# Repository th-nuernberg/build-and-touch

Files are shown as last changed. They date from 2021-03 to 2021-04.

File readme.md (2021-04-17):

# DIY VR Data Gloves 

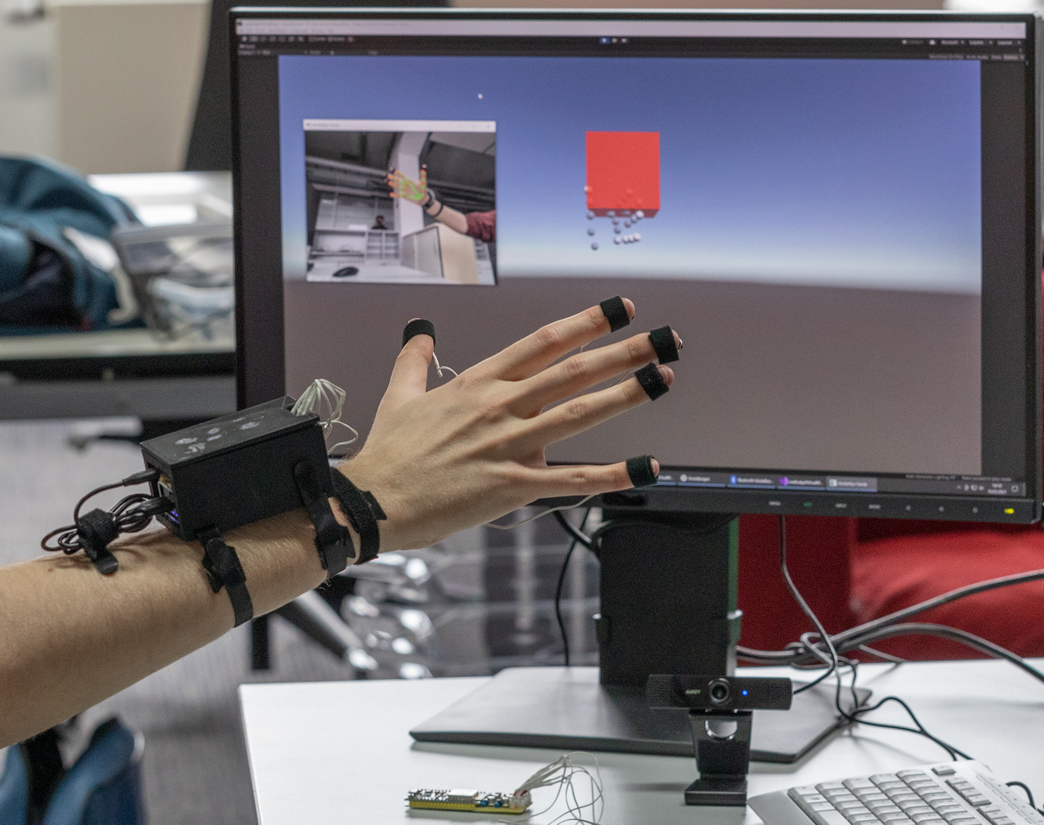
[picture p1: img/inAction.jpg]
Build and Touch in Action


## Overview
This repository provides an DIY approach to haptic feedback in virtual reality.
It is split into three components. 
- The tracking part, that is using Google's mediapipe for realtime detection of the users' fingers and hand position using an off-the-shelf webcam.
- The hardware part, that provides instruction to build the data gloves using a microcontroller and vibration actuators.
- A unity demo application.

## Work in Progress
This project is still in development and may undergo changes in the future.

## Instructions

Detailed instructions for each component can be found in the corresponding sub folders:
- [DIY Gloves](/data_gloves/readme.md)
- [Optical Tracking](/optical_tracking/readme.md)
- [Example Application](/unity_sample/readme.md)

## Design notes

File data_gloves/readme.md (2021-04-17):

# DIY Data Glove Build Instructions
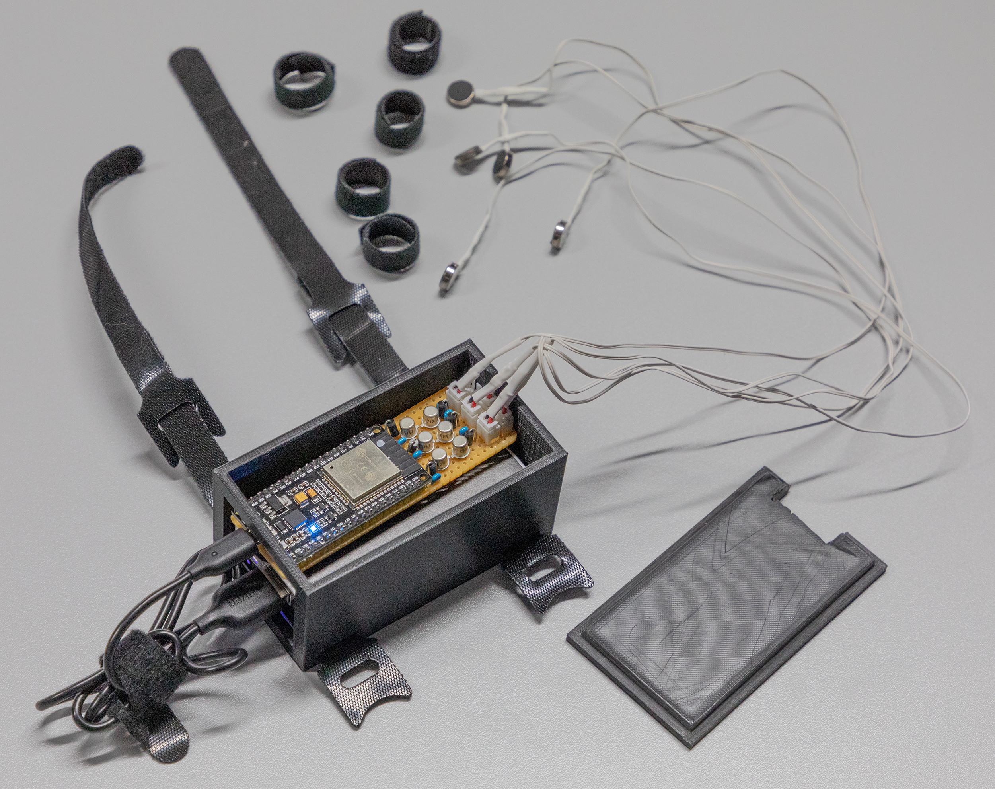
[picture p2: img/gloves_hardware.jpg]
Build and Touch in Action


The following document gives an overview of how the DIY data glove can be created. 
## Hardware Components
For one glove the following components are needed:

- 1 ESP32 microcontroller
- Power bank or other power source to power the ESP32 during use.
- **For each** finger (and palm) the following is required
    - 1 resistor (1KOhm)
    - 1 transistor (2N2222)
    - 1 diode (1N4001)
    - 1 capacitor (100nF)
    - 1 small vibration actuator

The required values may differ based on your selected components.

## Building the Hardware
The layout of the glove can be seen in the following overview.
Each actuator is connected with power and can be controlled through pulse-width modulation through an **analog** GPIO pin of the ESP32.
Depending on the exact module, the pins may vary and the spec sheet of your microcontroller should be consulted.
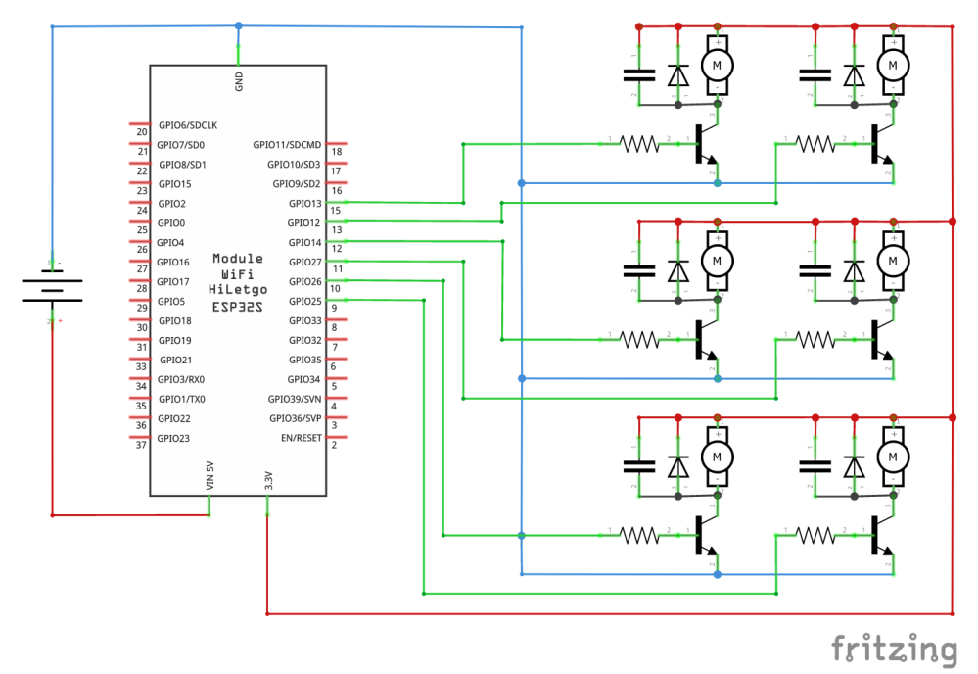
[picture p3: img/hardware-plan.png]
Hardware layout of the components


Instead of soldering the actuators directly to the other components or a soldering board it may be advised to use modular plugs instead. This way it is possible to only use a reduced set of actuators or replace a faulty one.

## Software for the Microcontroller
The ESP32 was flashed using the Arduino IDE.
The used code can be found in `data_gloves/src/hand_controller.ino`.
For easy identification, it is advised that each controller gets a unique name (e.g. left and right) if more than one esp is being used. For this, replace the string in `SerialBT.begin("Controller-right")` with your preferred name.

Depending on the used GPIO pins you may want to change the mapping of the pins in the source code.
Each finger (and the palm) get assigned an incrementing Id beginning at zero, that is later used to control the associated actuator.

The line `int fingerPins[] = { 12, 13, 14, 25, 26, 27 };` assigns each of these indices the associated GPIO pin. Therefore in this example the index finger is GPIO 13 and the PALM is mapped to GPIO 27. Feel free to change this if your pins differ.

## Connecting to Windows 10
With the hardware build and the flashed microcontroller the hardware is now ready for use.
For this connect the micro-usb port of the microcontroller to a power source. If the controller
provides an debug led it should be lit.

Connect the bluetooth dongle, if your computer doesn't have built-in bluetooth connectivity.
Going into Settings/Bluetooth the Controller should now show up when trying to connect to new devices.

## Testing the Controller
To test the implementation a simple string can be sent to the device. For this we can use [Bluetooth Serial Terminal](https://www.microsoft.com/de-de/p/bluetooth-serial-terminal/9wzdncrdfst8?activetab=pivot:overviewtab).

1. Refresh the device list and select the device you want to test (e.g. 'controller-right').
2. Press connect. We can send strings to the device.
3. Send the string "`0,255;`". One of the vibration motors should now be vibrating with full strength.
4. Send the string "`0,0;`". The same motor should stop vibrating.

If all went well the glove is ready for use in your projects.

## Protocol
The provided script of the microcontroller expects two values separated by a comma "`,`" followed by a semicolon "`;`". 
The first value is an integer that controls the actuator that should be triggered.
The second value is the intensity of the vibration. A value between 0-255. Zero is no vibration. 255 is full intensity (Note that depending on the used motor, it may not trigger for small values <50).
Multiple values can be sent with one message e.g.:
```
0,255;1,0;2,255;
```
Sets the first and third actuator to max and the second to zero intensity. All other connected actuators are unchanged!

## Fixation of the Actuators
The easy way to fixate the actuators to ones finger is the use of small velcro straps. 
For a more "sophisticated" method it is possible to the attach the actuators to a glove.
The image below shows an inner glove with six pockets in which the actuators can be placed. 
A bigger glove can worn above the inner glove so that the cables are out of the way during the usage of the glove.

TODO: Add image

## Printing an Enclosure
Additionally to the hardware an enclosure can be 3d-printed. This protects the hardware and also makes it easier to use.
The size of the case depends on the size of your hardware and power source.
An example OpenScad file is provided with 'data_gloves/enclosure.scad'.
The dimensions of the casing can be customized with the variables at the beginning of the file.
If the `strapholder` variable is set to `true` set of two holes on each side will be added, that can be used to fixate the device to ones hand (e.g. using velcro straps. See image at the top).

## Acknowledgements
These instructions are based on the initial version of the glove in "[Evaluation of different types of haptic feedback influencing the task-based presence and performance in virtual reality](https://dl.acm.org/doi/10.1145/3316782.3321536)". We thank the other team members involved there and especially Oliver Friedmann for the support during the initial development.

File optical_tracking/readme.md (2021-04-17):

# Optical Tracking

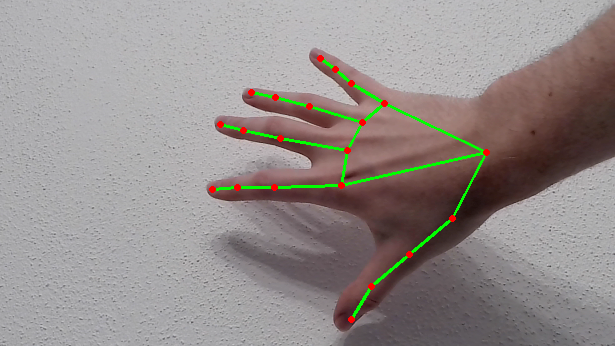
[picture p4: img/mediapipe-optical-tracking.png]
Build and Touch in Action


This folder contains the optical tracking script written in python. The application tries to connect to an tcp socket upon start and accesses the users webcam as an input device.
The hands landmarks get acquired through the use of [Google's mediapipe library](https://google.github.io/mediapipe/) and get set over tcp through the use of [Googles Protocol Buffers (protobuf)](https://developers.google.com/protocol-buffers/).
As the data is sent via protobuf it is possible to use any language that is supported by it on the receiving end.

## Building the Project
Before you start using any of the projects component, you first need to compile the protobuf file for your desired language.

To compile the protobuf files you need `protoc` in version 3 or higher. The current version can be found on https://github.com/protocolbuffers/protobuf.

```bash
protoc handdata.proto --csharp_out=../unity_sample/src/build-and-touch/Assets/Scripts --python_out=src
```

To build the protobuf files for another languages see: https://developers.google.com/protocol-buffers/docs/tutorials.

# Install the Requirements

1. Optionally create a python virtual environment (e.g. with `virtualenv -p python3 <name>`) and activate it (e.g. `source <name>/bin/activate`).
2. Install all requirements using `pip install -r requirements.txt`
3. Optionally configure the python scripts to your needs.
4. Build the protobuf file if not already done.
5. Execute main.py (NOTICE: The script tries to immediately connect to the IP-Address and port specified in `connection.py`. If nothing listens on this socket the application will close.)

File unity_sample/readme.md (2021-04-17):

# Example VR Application
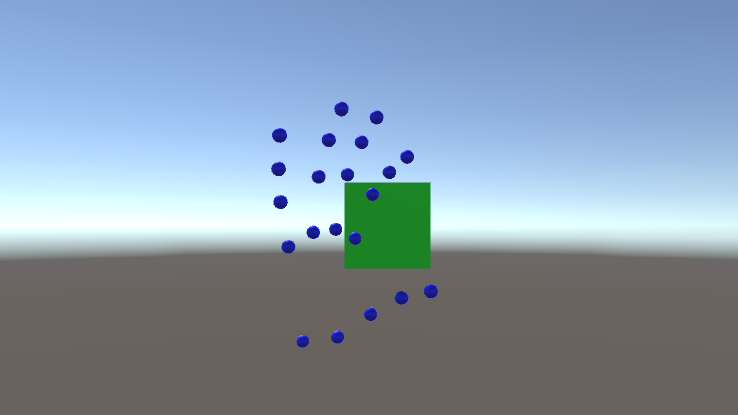
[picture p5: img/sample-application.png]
Build and Touch in Action


This folder contains an simple example that combines the DIY data gloves and the media optical tracking into a unity demo.

## Running the Project

Notice: While the hand tracking works in Unity on Linux, OSX and Windows, we provide for now a bluetooth implementation for Windows only. 

1. Follow the instructions to setup the optical tracking
2. Open the folder `build-and-touch` with Unity version `2020.4.x` or later.
3. Import the required dependencies (see next section).
4. (Optional) Enable the data gloves (Windows)
    1. Connect the datagloves with Windows 10
    2. Open "Bluetooth & other devices" in the settings
    3. Click on "More Bluetooth options" on the right side
    4. Select the tab "COM Ports"
    5. Copy the incoming com port for the right hand controller 
    6. Select the "Manager" GameObject in the unity hierarchy
    7. Paste the value into the `Right Hand Com Port` field in the inspector (For serial ports greater than 9 `\\.\` needs to be added in front of the serial port. See https://support.microsoft.com/en-us/topic/howto-specify-serial-ports-larger-than-com9-db9078a5-b7b6-bf00-240f-f749ebfd913e)
    8. Repeat steps 5-7 for the left hand controller
5. Enter Unity play mode.
6. Start the optical tracking python program. The hands now should be shown in Unity.

## Required Dependencies
The project requires the following dependencies to successfully compile, these files need to be manually added to the unity assets folder (for now):

- Google.Protobuf.dll - Select the current 3.x C# release https://github.com/protocolbuffers/protobuf/releases
- System.Buffers.dll - https://www.nuget.org/packages/System.Buffers/
- System.Memory.dll - https://www.nuget.org/packages/System.Memory/
- System.Runtime.CompilerServices.Unsafe.dll - https://www.nuget.org/packages/System.Runtime.CompilerServices.Unsafe/

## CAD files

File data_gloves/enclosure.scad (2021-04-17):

// dimensions of the device that should be enclosed (in mm)
h = 35;
width = 40;
length = 87;

thickness = 3; // thickness of the walls

//cutout
cWidth = 26;
cLength = 17;

// Wheter to provide a hole for the velcro-streps
strapholder = true;
sWidth = 13;
sHeight = 3;

// Calculated properties for later use
dthick = 2*thickness;

 height = strapholder ? h + sHeight : h;

// outer dimensions
oLength = length+dthick;
oWidth = width+dthick;
oHeight = height+dthick;

// Box
difference() {    
    cube([oLength,oWidth,oHeight]);       
    
    if(strapholder){
        translate(v=[dthick, - 0.5, thickness])  cube([sWidth, oWidth+1, sHeight]);
        translate([oLength-dthick-sWidth, - 0.5, thickness])  cube([sWidth, oWidth+1, sHeight]);        
    }
       
    translate(v=[thickness,thickness,thickness])  cube([length,width, oHeight]);
    translate(v=[length,dthick,dthick])  cube([dthick*2, width-dthick, height-dthick ]);        
}

// Lid
translate(v=[0, width+10, 0]){
    difference(){
            // Lid itself
        union() {
            cube([oLength,oWidth,thickness]);
            translate(v=[thickness, thickness, thickness]) cube([length, width, thickness]);            
        }
            //cutout
         translate(v=[0, width/2, thickness]) cube([cLength+ thickness, cWidth, dthick+1], center = true);             
    }      
}

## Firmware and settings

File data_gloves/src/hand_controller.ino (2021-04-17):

/**
* Map String value to analog ping
* esp32 has no analogWrite, use ledcWrite
*/
#include "BluetoothSerial.h"
#include "Arduino.h"

uint8_t THUMB = 0;
uint8_t INDEX = 1;
uint8_t MIDDLE = 2;
uint8_t RING = 3;
uint8_t PINKY = 4;
uint8_t PALM = 5;

int fingerPins[] = { 12, 13, 14, 25, 26, 27 };

BluetoothSerial SerialBT;
String line;

void setup() 
{
    SerialBT.begin("controller-right");
    
    // binding fingers (channel) to GPIO pins
    mapChannelToGPIO(THUMB, fingerPins[THUMB]);
    mapChannelToGPIO(INDEX, fingerPins[INDEX]);
    mapChannelToGPIO(MIDDLE, fingerPins[MIDDLE]);
    mapChannelToGPIO(RING, fingerPins[RING]);
    mapChannelToGPIO(PINKY, fingerPins[PINKY]);
    mapChannelToGPIO(PALM, fingerPins[PALM]);
    
    // set pinmode
    for (int i=0; i<sizeof(fingerPins); i++)
    {
        pinMode(fingerPins[i], OUTPUT);
    }
}

/**
* channel = channel for ledcWrite esp32 - pin = GPIO with vibrator
*/
void mapChannelToGPIO(int channel, int pin)
{
    ledcSetup(channel, 5000, 8);
    ledcAttachPin(pin, channel);
}

void loop() 
{
    if(SerialBT.available())
    {
        char input = SerialBT.read();
        if(input != ';' && input != '\n')
        {
            line += input;
        }
        else 
        { 
            controlVib(line); line = ""; 
        }
    }
}

void btPrint(String text)
{
    for(int i=0; i<text.length(); i++){
        SerialBT.write(text[i]);
    }
}

void btPrintln(String text)
{
    btPrint(text);
    SerialBT.write('\n');
}

/**
* valuePair = CHANNEL, INTENSITY - e.g. 0,255 - only one at a time!
*/
void controlVib(String valuePair)
{
    String s_channel = getValue(valuePair, ',', 0);
    String s_intensity = getValue(valuePair, ',', 1);

    int channel = s_channel.toInt();
    int intensity = s_intensity.toInt();

    btPrintln(s_channel + "," + s_intensity);

    if (channel >= 0
        && channel < sizeof(fingerPins)
        && intensity >= 0
        && intensity <= 255)
    {
        ledcWrite(channel, intensity); 
    }
}

// https://stackoverflow.com/questions/9072320/split-string-into-string-array/14824108#14824108
String getValue(String data, char separator, int index)
{
    int found = 0;
    int strIndex[] = {0, -1};
    int maxIndex = data.length()-1;
    for (int i=0; i<=maxIndex && found<=index; i++)
    {
        if (data.charAt(i)==separator || i==maxIndex)
        {
            found++;
            strIndex[0] = strIndex[1]+1;
            strIndex[1] = (i == maxIndex) ? i+1 : i;
        }
    }
    return found>index ? data.substring(strIndex[0], strIndex[1]) : "";
}
